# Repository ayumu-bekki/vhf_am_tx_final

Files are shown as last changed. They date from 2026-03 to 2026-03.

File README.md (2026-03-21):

# VHF AM 送信用ファイナル段

VHF帯(144MHz)AM送信用ファイナル段の試験基板です。

## 仕様

| 項目 | 値 |
|---|-----|
| 電源電圧 | 5V〜7.2V |
| 対応MOSFET | 2SK3074 / HTL7G06S006P |

### 出力電力・入力レベル

| 電源 | MOSFET | 出力電力 | 入力レベル |
|---|---|---|---|
| 5V | 2SK3074 | 125mW | 10mW (+10dBm / 2.0Vpp) |
| 7.2V | 2SK3074 | 500mW | 50mW (+17dBm / 4.5Vpp) |
| 5V | HTL7G06S006P | 750mW | 10mW (+10dBm / 2.0Vpp) |
| 7.2V | HTL7G06S006P | 1500mW | 20mW (+13dBm / 2.8Vpp) |

---

## インダクタの製作

### L2(フェライトコアチョークコイル)

- コア : 43材フェライトコア(例：FT-37-43)
- 線材 : 0.65mm ポリウレタン銅線
- 巻き数
  - 3.3μH : 3回巻き

### L1, L3, L4, L5(空芯コイル)

- 線材 : 0.8mm ポリウレタン銅線
- コア : 空芯(外径5mmの軸を型に使用)
- 巻き数
  - 50nH : 3回巻き
  - 80nH : 4回巻き

---

## MOSFETごとの実装変更

### 2SK3074 の場合

- 回路図通りに実装する

### HTL7G06S006P の場合

- 以下のパーツを変更する

| 部位 | 部品 | 変更内容 |
|---|---|---|
| 入力マッチング | C3 | 50pF トリマ |
| 出力マッチング | L3 | 40nH(2〜3回巻き) |
| 出力マッチング | C8 | 47pF を実装する |

---

## 調整方法

### 必要な機器

- 電流計
- NanoVNA
- TinySA

---

### 1. バイアス調整(アイドリング電流の設定)

FETがAB級リニアアンプとして動作するよう、無信号時のアイドリング電流を設定します。

**準備**

1. RF信号は入力しない
2. RV1を絞る(ゲート電圧が最低になる方向)
3. 電源ラインに電流計を直列に接続

**手順**

1. 電源を入れる(この時点では数mA程度しか流れない)
2. RV1をゆっくり回していくと、電流が流れ始める点がある
3. 電流が **20〜30mA** になる位置でRV1を止める

---

### 2. 入力マッチング調整

NanoVNAを使って、アンプ入力のインピーダンスを50Ωに合わせます。
電源は入れた状態で測定する必要があります。

1. NanoVNAを144MHz中心にスキャン設定し、S11(反射係数 / SWR)を表示
2. NanoVNA CH0をアンプの入力コネクタ(J1)に接続
3. スミスチャートまたはSWRグラフを見ながら、トリマコンデンサ **C1** を回して **144MHzでSWR最小** となる点に合わせる

---

### 3. 出力マッチング調整

実際に電源・RF信号を入力して出力パワーを最大化します。

1. 入力(J1)に144MHzの信号源を接続
2. 出力(J3)に30dBアッテネータ → TinySA を接続
3. TinySAで144MHz付近のスペクトラムを表示
4. アンテナ側トリマ **C6** を回してピークが最大になる点を探す
5. FET側トリマ **C4** を回してさらにピークが高くなる点を探す
6. C6とC4を交互に調整し、ピーク点を追い込む

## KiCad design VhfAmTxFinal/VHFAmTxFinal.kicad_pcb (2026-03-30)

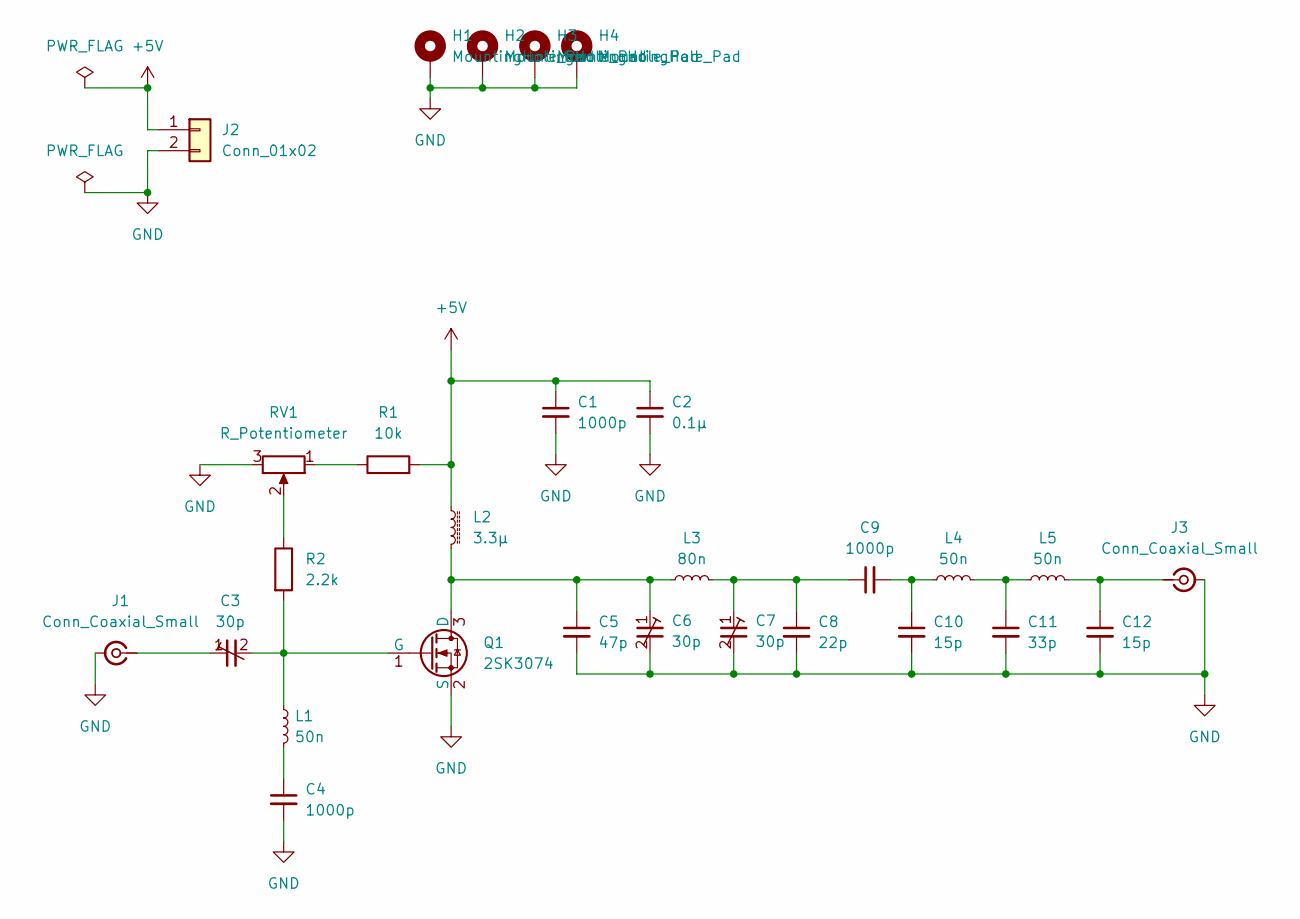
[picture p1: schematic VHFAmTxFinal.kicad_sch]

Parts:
C1, C4, C9: 1000p; C_0603_1608Metric_Pad1.08x0.95mm_HandSolder
C2: 0.1μ; C_0603_1608Metric_Pad1.08x0.95mm_HandSolder
C3, C6, C7: 30p; Ceramic_Trimmer_Capacitors_THT
C5: 47p; C_0603_1608Metric_Pad1.08x0.95mm_HandSolder
C8: 22p; C_0603_1608Metric_Pad1.08x0.95mm_HandSolder
C10, C12: 15p; C_0603_1608Metric_Pad1.08x0.95mm_HandSolder
C11: 33p; C_0603_1608Metric_Pad1.08x0.95mm_HandSolder
H1, H2, H3, H4: MountingHole_Pad; MountingHole_3.2mm_M3_Pad_Via
J1, J3: Conn_Coaxial_Small; SMA_S-063-49-TGG_EdgeMount_Horizontal
J2: Conn_01x02; JST_XH_S2B-XH-A_1x02_P2.50mm_Horizontal
L1, L4, L5: 50n; Air_Core_Inductor_8mm
L2: 3.3μ; Choke_Inductor_10mm
L3: 80n; Air_Core_Inductor_8mm
Q1: 2SK3074; SOT-89-3_Handsoldering
R1: 10k; R_0603_1608Metric_Pad0.98x0.95mm_HandSolder
R2: 2.2k; R_0603_1608Metric_Pad0.98x0.95mm_HandSolder
RV1: R_Potentiometer; Potentiometer_Vishay_T73YP_Vertical

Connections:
+5V: C1.1, C2.1, J2.1, L2.1, R1.2
GND: C1.2, C2.2, C4.2, C5.2, C6.2, C7.2, C8.2, C10.2, C11.2, C12.2, H1.1, H2.1, H3.1, H4.1, J1.2 (Ext), J2.2, J3.2 (Ext), Q1.2 (S), RV1.3
unnamed: C4.1, L1.2
unnamed: C7.1, C8.1, C9.1, L3.2
unnamed: C9.2, C10.1, L4.1
unnamed: C11.1, L4.2, L5.1
unnamed: C3.1, J1.1 (In)
unnamed: C12.1, J3.1 (In), L5.2
unnamed: C5.1, C6.1, L2.2, L3.1, Q1.3 (D)
unnamed: C3.2, L1.1, Q1.1 (G), R2.2
unnamed: R1.1, RV1.1
unnamed: R2.1, RV1.2

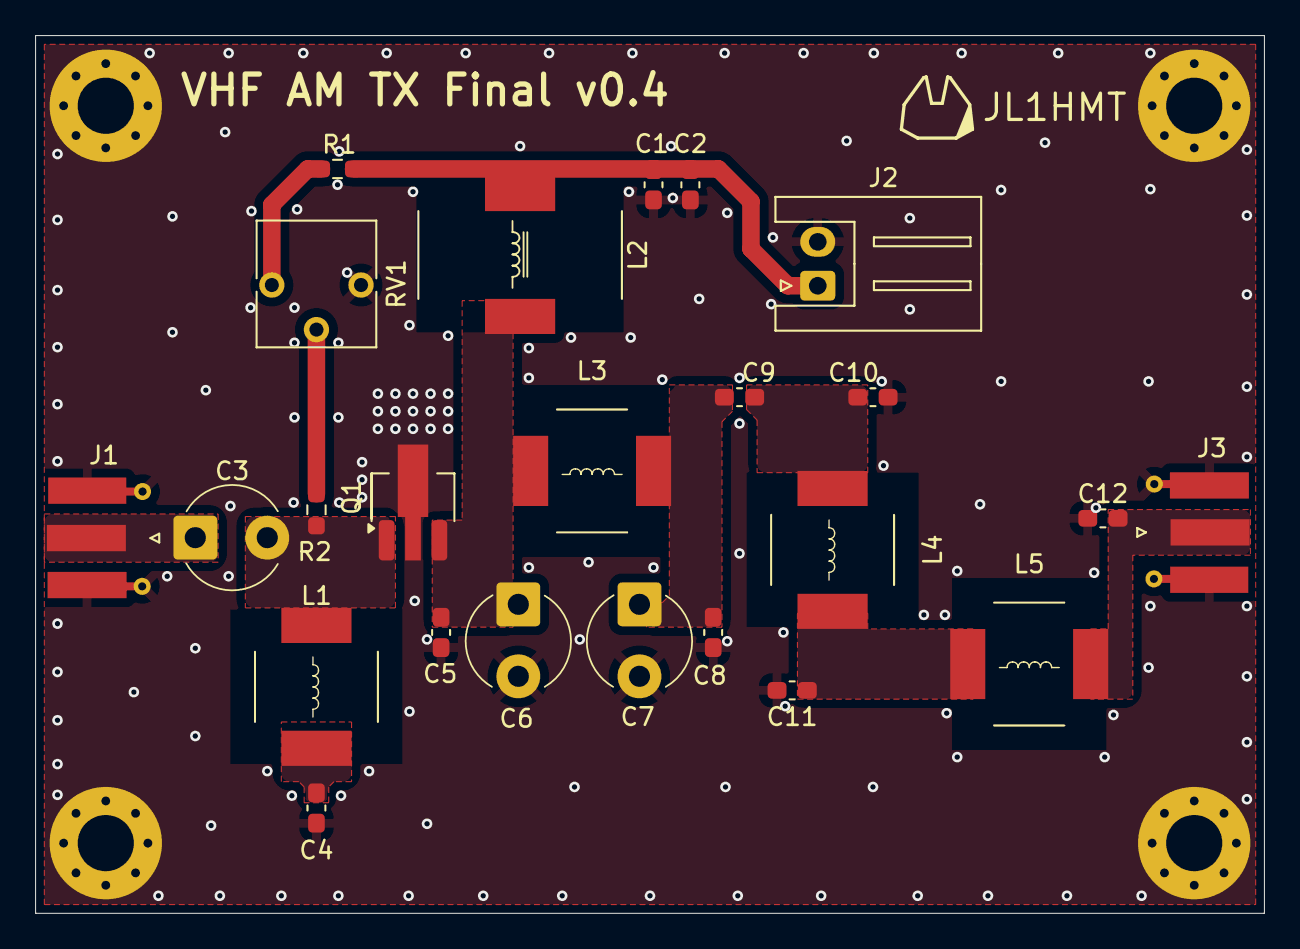
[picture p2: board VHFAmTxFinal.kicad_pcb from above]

Board: 2 copper layers, 70.0 x 50.0 mm, 28 parts (0 on the bottom side), 12 nets.

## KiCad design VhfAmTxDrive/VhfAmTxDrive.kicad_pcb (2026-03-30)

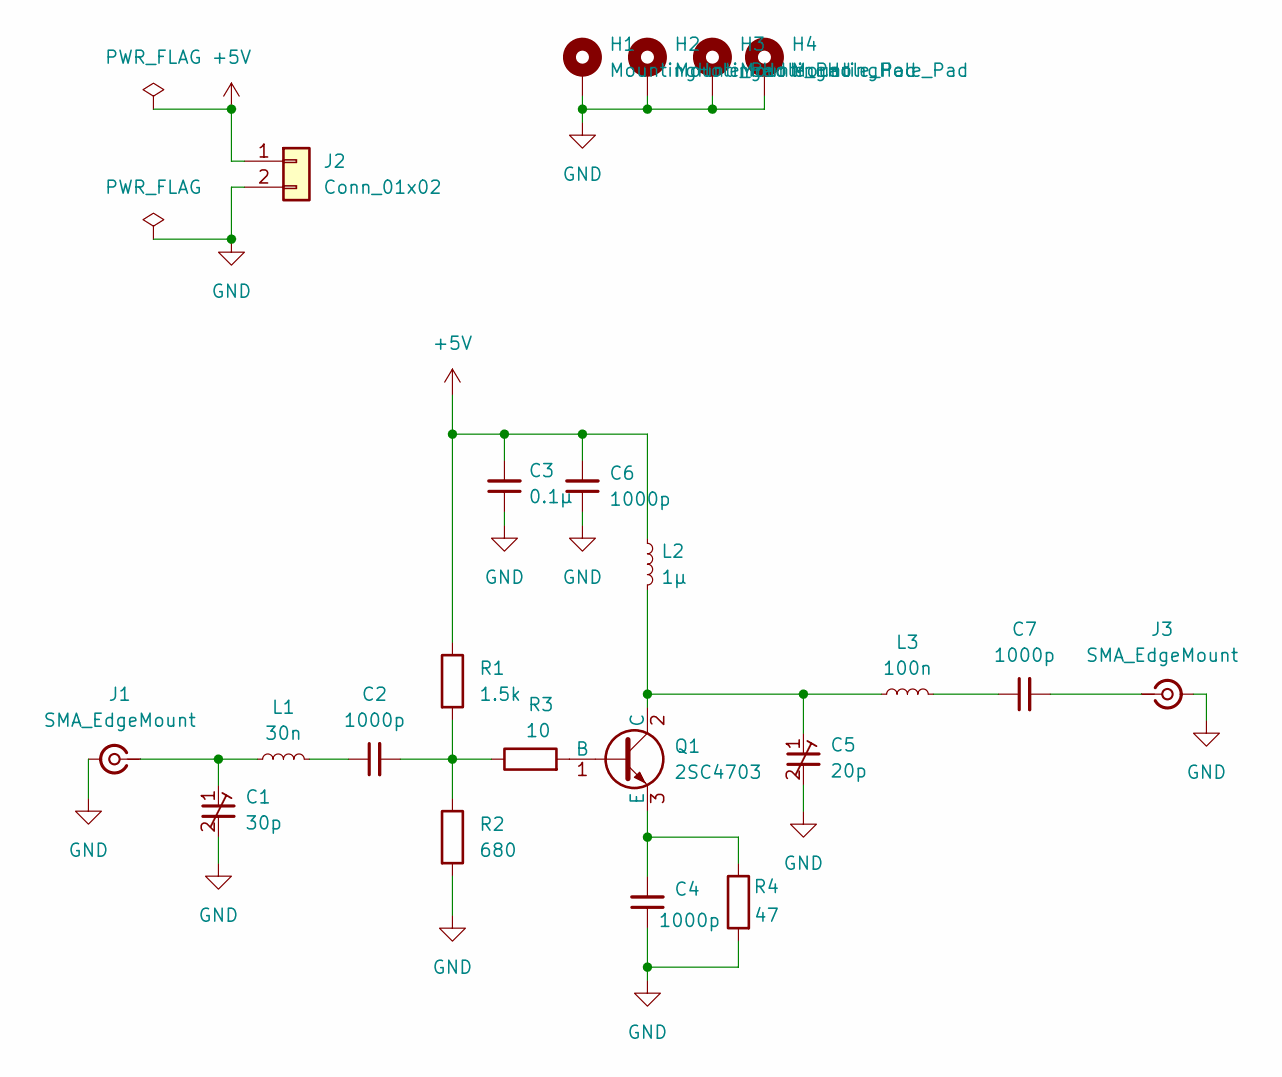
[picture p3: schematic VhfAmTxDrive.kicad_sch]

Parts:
C1: 30p; Ceramic_Trimmer_Capacitors_THT
C2, C4, C6, C7: 1000p; C_0603_1608Metric_Pad1.08x0.95mm_HandSolder
C3: 0.1μ; C_0603_1608Metric_Pad1.08x0.95mm_HandSolder
C5: 20p; Ceramic_Trimmer_Capacitors_THT
H1, H2, H3, H4: MountingHole_Pad; MountingHole_3.2mm_M3_Pad_Via
J1, J3: SMA_EdgeMount; SMA_S-063-49-TGG_EdgeMount_Horizontal
J2: Conn_01x02; JST_XH_S2B-XH-A_1x02_P2.50mm_Horizontal
L1: 30n; Air_Core_Inductor_8mm
L2: 1μ; Air_Core_Inductor_8mm
L3: 100n; Air_Core_Inductor_12mm
Q1: 2SC4703
R1: 1.5k; R_0603_1608Metric_Pad0.98x0.95mm_HandSolder
R2: 680; R_0603_1608Metric_Pad0.98x0.95mm_HandSolder
R3: 10; R_0603_1608Metric_Pad0.98x0.95mm_HandSolder
R4: 47; R_0603_1608Metric_Pad0.98x0.95mm_HandSolder

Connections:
+5V: C3.2, C6.2, J2.1, L2.1, R1.1
GND: C1.2, C3.1, C4.1, C5.2, C6.1, H1.1, H2.1, H3.1, H4.1, J1.2 (Ext), J2.2, J3.2 (Ext), R2.2, R4.2
unnamed: C2.1, L1.2
unnamed: C2.2, R1.2, R2.1, R3.1
unnamed: C7.1, L3.2
unnamed: C1.1, J1.1 (In), L1.1
unnamed: C7.2, J3.1 (In)
unnamed: Q1.1 (B), R3.2
unnamed: C5.1, L2.2, L3.1, Q1.2 (C)
unnamed: C4.2, Q1.3 (E), R4.1

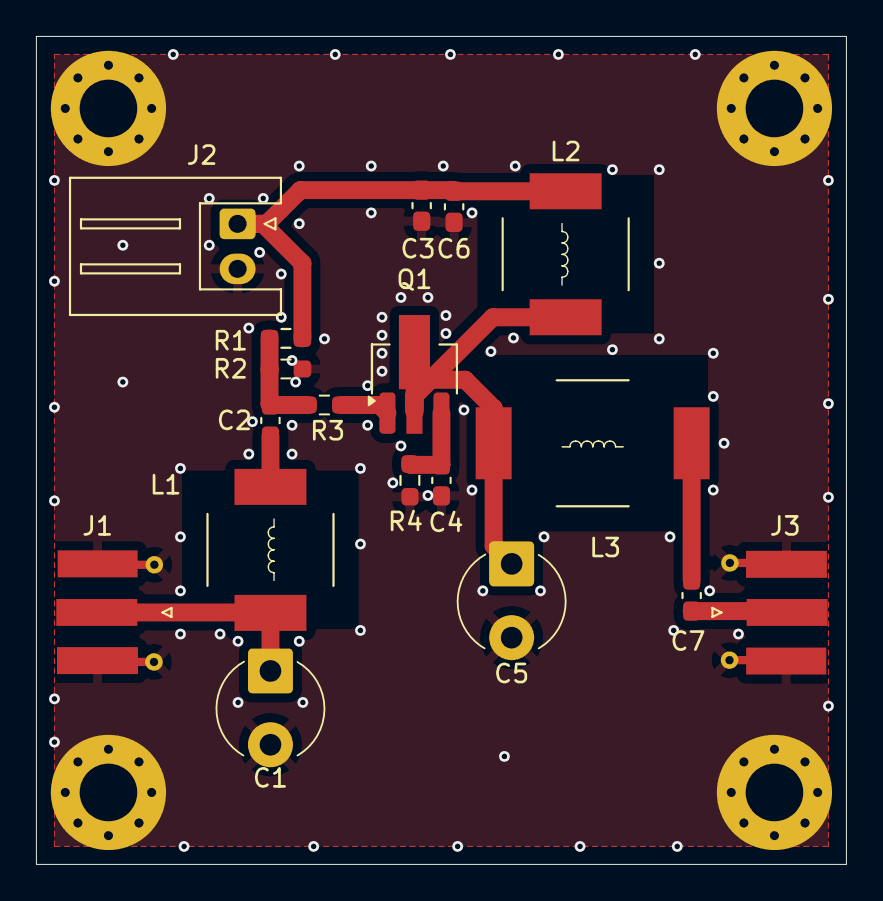
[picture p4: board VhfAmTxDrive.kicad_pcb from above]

Board: 2 copper layers, 45.0 x 46.0 mm, 22 parts (0 on the bottom side), 10 nets.

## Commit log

2026-03-11 add pcb
    [VHFAmTxFinal.kicad_pcb, VHFAmTxFinal.kicad_sch]
2026-03-11 バイアス電圧用調整・安全用抵抗の追加とレイアウト修正
    [VHFAmTxFinal.kicad_pcb, VHFAmTxFinal.kicad_sch]
2026-03-11 HTL7G06S006Pの対応 READMEアップデート
    [VHFAmTxFinal.kicad_pcb, VHFAmTxFinal.kicad_sch]
2026-03-13 基板のレイアウト修正 v0.3
    [VHFAmTxFinal-B_Cu.gbr, VHFAmTxFinal-B_Mask.gbr, VHFAmTxFinal-B_Paste.gbr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]
2026-03-21 ドキュメント修正ドライブ段を追加
    [VHFAmTxFinal.kicad_sch, VhfAmTxDrive.kicad_pcb, VhfAmTxDrive.kicad_sch]
2026-03-30 基板修正
    [VHFAmTxFinal.kicad_pcb, VHFAmTxFinal.kicad_sch, VhfAmTxDrive.kicad_pcb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]
